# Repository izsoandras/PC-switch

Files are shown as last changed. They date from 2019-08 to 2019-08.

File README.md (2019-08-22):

# PC-switch
Simple gadget to turn on my PC remotely. I could have used my motherboards Wake on LAN service, but it is disabled on my student hostel's network.

A webserver is running on the ESP8266 with a very simple REST API. After authentication the client side offers a few buttons. These buttons send http requests to the proper URI address, and the ESP performs the required action.
The available options:
- **Turn on:** imitates the pressing of the power button
- **Reset:** imitates the pressing of the reset button
- **Refresh:** asks the server for the current state of the PC (does not work at this time)

The webpage also displays the current state of the PC.

The circuit is fairly simple. You can plug the board on the place of the front panel header of the mother board. Since I used long pin headers, the wires running to the chassis's front panel can be plugged in aswell
I used two FETs paralell to the power and reset button, to imitate the press of those buttons. There are also LEDs on the same pins as the FETs' gates for debug purposes.
The PC's state could be read from the Power and HDD LEDs' state.

The current problem is that, I did not measure the LEDs' active state, just assumed it's high active. Unfortunately my motherboard is more complicated than that.
If the PC os off, the + pin of the LED is on 5V, and the - pin is on 3V. If it's turned on the pins are on 3V and 0.1V respectively.

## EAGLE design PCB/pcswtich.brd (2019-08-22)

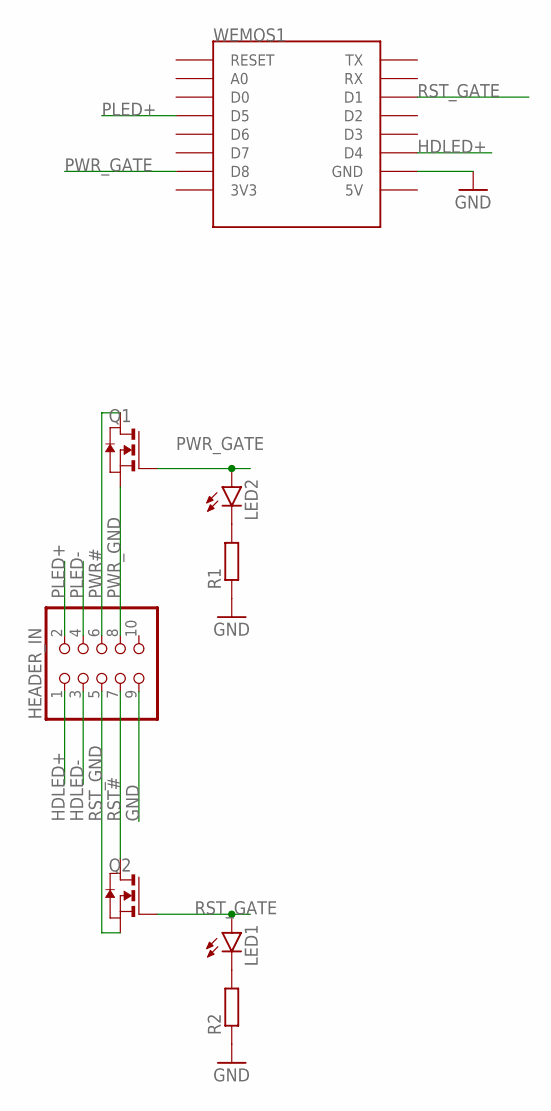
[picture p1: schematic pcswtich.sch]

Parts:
HEADER_IN: PINHD-2X5; 2X05
LED1, LED2: LEDCHIPLED_0805; CHIPLED_0805
Q1, Q2: NMOSSOT23; SOT-23
R1, R2: R-EU_R0805; R0805
WEMOS1: WEMOS-D1-MINI

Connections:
GND: HEADER_IN.9, R1.1, R2.1, WEMOS1.GND
HDLED+: HEADER_IN.1, WEMOS1.D4
HDLED-: HEADER_IN.3
unnamed: LED2.C, R1.2
unnamed: LED1.C, R2.2
PLED+: HEADER_IN.2, WEMOS1.D5
PLED-: HEADER_IN.4
PWR#: HEADER_IN.6, Q1.1 (D)
PWR_GATE: LED2.A, Q1.3 (G), WEMOS1.D8
PWR_GND: HEADER_IN.8, Q1.2 (S)
RST#: HEADER_IN.7, Q2.1 (D)
RST_GATE: LED1.A, Q2.3 (G), WEMOS1.D1
RST_GND: HEADER_IN.5, Q2.2 (S)

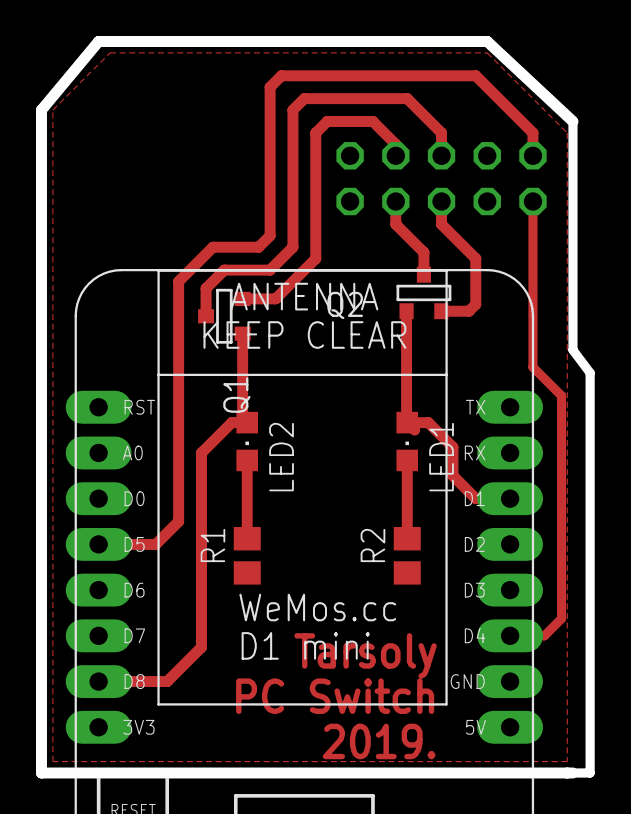
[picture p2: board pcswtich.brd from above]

Board: 2 copper layers, 30.5 x 40.6 mm, 8 parts (1 on the bottom side), 11 nets.

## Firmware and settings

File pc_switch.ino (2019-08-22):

#include<ESP8266WiFi.h>
#include<ESP8266mDNS.h>
#include<ESP8266WebServer.h>
#include<FS.h>
#include<ArduinoOTA.h>

//D1 = rerset
#define PC_RST 5
//D8 = power
#define PC_PWR 15
//D5 = power LED
#define PC_PWR_LED 14
//D4 = HDD LED
#define PC_HDD_LED 2

//SSID of the WiFi network to connect to
const char* ssid = "1601-rotacioskappa_p";
//Password of the WiFi network to connect to
const char* password = "16Konyharuha01";
//mDNS address
const char* dns = "pcswitch";//.local

//authentication data for the web server
const char* username = "seedow";
const char* userpwd = "turnon";
//authentication for OTA
const char* ota_user = "pcswitch_ota";
const char* ota_pwd = "secretpwdOta123";
//server instance
ESP8266WebServer server(80);

void connectWiFi();
void setupServer();
void turnOn();
void initSPIFFS();
void initOTA();
void getPcState();
void kill();
bool handleReadFile(String fileName);
void setup(){
    //start serial
    Serial.begin(115200);
    //put ESP to station mode
    WiFi.mode(WIFI_STA);
    //print MAC address
    Serial.print("MAC: ");
    Serial.println(WiFi.macAddress());
    //init the file system
    initSPIFFS();
    //connect to the WiFi network
    WiFi.begin(ssid, password);
    connectWiFi();
    //start mDNS server
    if(!MDNS.begin(dns))
        Serial.println("MDSN setup error");
    else
        Serial.println("MDNS started");
    //set up the webserver
    setupServer();
    //initialize over the air update
    initOTA();
    //configure pin modes
    pinMode(PC_PWR, OUTPUT);
    digitalWrite(PC_PWR, LOW);
    pinMode(PC_RST, OUTPUT);
    digitalWrite(PC_RST, LOW);
    pinMode(PC_HDD_LED, INPUT);
    pinMode(PC_PWR_LED, INPUT);
}

//call handlers of the servers
void loop(){
    ArduinoOTA.handle();
    server.handleClient();
}

void initSPIFFS(){
    //start the SPIFFS file system
    SPIFFS.begin();
    //print out the available files on serial
    Dir dir = SPIFFS.openDir("/");
    while (dir.next()) {
      String fileName = dir.fileName();
      size_t fileSize = dir.fileSize();
      Serial.printf("FS File: %s, size: %d\n", fileName.c_str(), fileSize);
    }
    Serial.printf("\n");
  
}

void connectWiFi(){
    //wait till connection is established to the WiFi
    Serial.print("Connecting to ");
    Serial.println(ssid);
    while(WiFi.status() != WL_CONNECTED){
        delay(1000);
        Serial.print('*');
    }
    //print the IP address
    Serial.println();
    Serial.print("IP address: ");
    Serial.println(WiFi.localIP());
}

void setupServer(){
    //sen the index.html on empty address
    server.on("/", HTTP_GET, []{
        if(!server.authenticate(username, userpwd))
            return server.requestAuthentication();
        
        if(!handleReadFile("/index.html"))
            server.send(404, "text/plain", "Not Found");
    });
    //call the handlers of the requests
    server.on("/pcstate", HTTP_GET, getPcState);
    server.on("/hddstate", HTTP_GET, getHddState);
    server.on("/turnon", HTTP_POST, turnOn);
    server.on("/reset", HTTP_POST, reset);
    server.on("/kill", HTTP_POST, kill);
    
    server.onNotFound(handleNotFound);
    //start server
    server.begin();
    Serial.println("Server started");
}

//Streams the requested file if it exists and returns with true, returns with false otherwise
bool handleReadFile(String fileName){
    Serial.println("File read: "+fileName);
    if(SPIFFS.exists(fileName)){
        File file = SPIFFS.open(fileName, "r");
        server.streamFile(file, "html");
        file.close();
        return true;
    } else{
        return false;
    }
}
//reads the PC's power LED to decide if it is turned on
void sendPcState(){
    Serial.print("PC state: ");
    Serial.println(digitalRead(PC_PWR_LED));
    if(digitalRead(PC_PWR_LED) == HIGH)
        server.send(200, "text/plain", "On");
        
    else
        server.send(200, "text/plain", "Off");
}
//reads the PC's power LED to decide if it is turned on
void sendHddState(){
    Serial.print("HDD state: ");
    Serial.println(digitalRead(PC_HDD_LED));
    if(digitalRead(PC_HDD_LED) == HIGH)
        server.send(200, "text/plain", "On");
    else
        server.send(200, "text/plain", "Off");
}
//checks authentication, logs the requests and calls the appropriate function
void getPcState(){
    if(!server.authenticate(username, userpwd))
        return server.send(401, "text/plain", "Unauthorized");
    
    Serial.println("Get PC state");
    sendPcState();
}
//checks authentication, logs the requests and calls the appropriate function
void getHddState(){
    if(!server.authenticate(username, userpwd))
        return server.send(401, "text/plain", "Unauthorized");

    Serial.println("Get HDD state");
    sendHddState();
}
// turns on the PC by shortcircuiting the pins of the power switch
void turnOn(){
    if(!server.authenticate(username, userpwd))
        return server.send(401, "text/plain", "Unauthorized");

    Serial.println("Turn on request");
    digitalWrite(PC_PWR, HIGH);
    delay(500);
    digitalWrite(PC_PWR, LOW);
    
    delay(2000);
    sendPcState();
}
// resets the PC by shortcircuiting the pins of the power switch
void reset(){
    if(!server.authenticate(username, userpwd))
        return server.send(401, "text/plain", "Unauthorized");

    Serial.println("Reset request");
    digitalWrite(PC_RST, HIGH);
    delay(500);
    digitalWrite(PC_RST, LOW);
    
    delay(2000);
    sendPcState();
}

void kill(){
    if(!server.authenticate(username, userpwd))
        return server.send(401, "text/plain", "Unauthorized");

    Serial.println("Turn on request");
    digitalWrite(PC_PWR, HIGH);
    delay(4000);
    digitalWrite(PC_PWR, LOW);
    
    delay(2000);
    sendPcState();
}
// sends error 404 if the requested file can not be found
void handleNotFound(){
    if(!server.authenticate(username, userpwd))
        return server.send(401, "text/plain", "Unauthorized");

    if(!handleReadFile(server.uri()))
            server.send(404, "text/plain", "Not Found");
}
//initializes OTA, sets the handlers
void initOTA(){
    ArduinoOTA.setHostname(ota_user);
    ArduinoOTA.setPassword(ota_pwd);

  ArduinoOTA.onStart([]() {
    Serial.println("OTA start");
  });
  ArduinoOTA.onEnd([]() {
    Serial.println("\nOTA End");
  });
  ArduinoOTA.onProgress([](unsigned int progress, unsigned int total) {
    Serial.printf("Progress: %u%%\r", (progress / (total / 100)));
  });
  ArduinoOTA.onError([](ota_error_t error) {
    Serial.printf("Error[%u]: ", error);
    if (error == OTA_AUTH_ERROR) Serial.println("Auth Failed");
    else if (error == OTA_BEGIN_ERROR) Serial.println("Begin Failed");
    else if (error == OTA_CONNECT_ERROR) Serial.println("Connect Failed");
    else if (error == OTA_RECEIVE_ERROR) Serial.println("Receive Failed");
    else if (error == OTA_END_ERROR) Serial.println("End Failed");
  });
  ArduinoOTA.begin();
  Serial.println("OTA ready");
}
